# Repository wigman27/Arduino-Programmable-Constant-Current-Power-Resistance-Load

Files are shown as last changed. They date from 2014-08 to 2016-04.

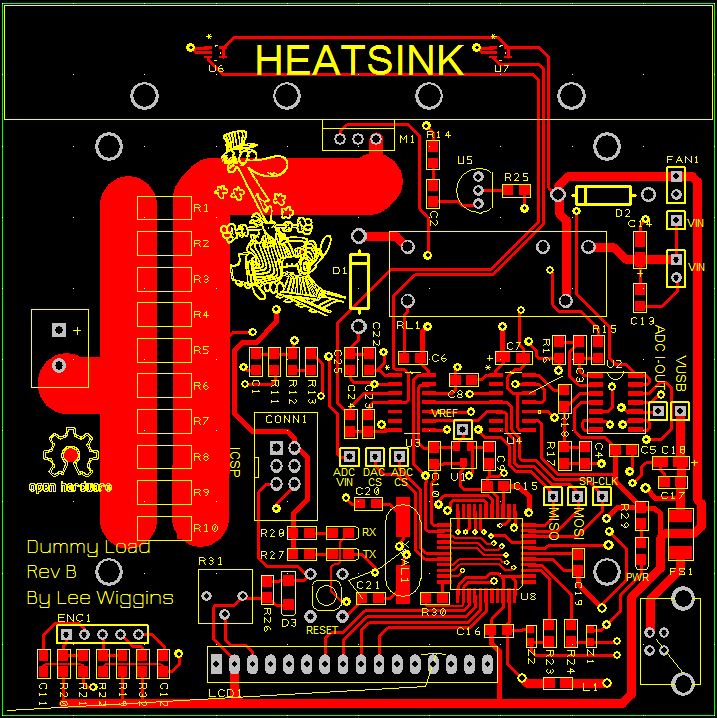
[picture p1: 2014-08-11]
Design Spark/rev 2/Top Layer.JPG

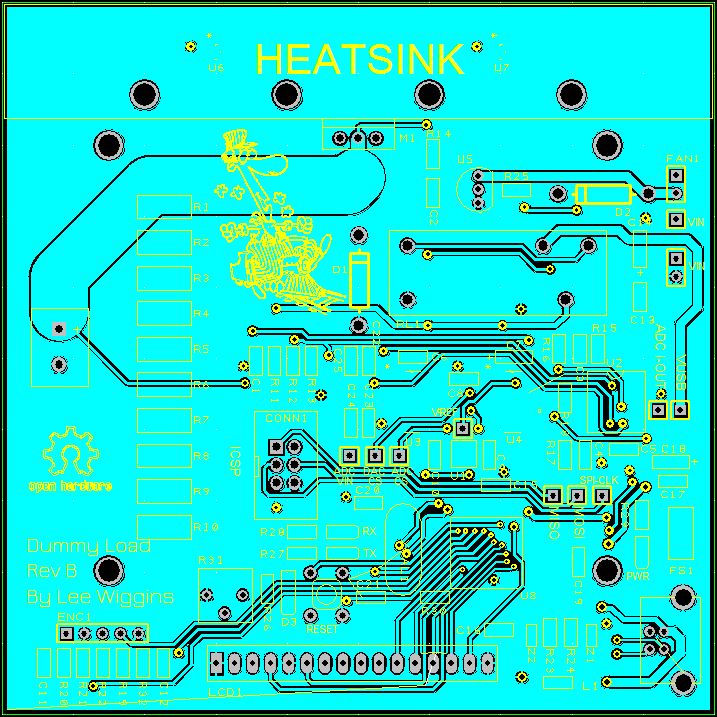
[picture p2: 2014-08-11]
Design Spark/rev 2/Bottom Layer.JPG

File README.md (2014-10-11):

Arduino-Programmable-Constant-Current-Power-Resistance-Load
===========================================================

This is all of the code, datasheets and design files for [my instructable](http://www.instructables.com/id/Arduino-Programmable-Constant-Current-Power-Resist/ "Arduino Programmable Constant Current Power Resistance Load") 

I also have boards available for sale on [Tindie](https://www.tindie.com/products/Wigman27/pcb-for-arduino-programmable-constant-current-power-resistance-load/) for $10 each
<p></p>

* Arduino - It contains the Arduino code that we will be talking about here, within the dummy load folder. It also contains all of the 3rd party libraries I have used.
* Datasheets - It contains all of the datasheets for the major components used within the project.
* DesignSpark - I have used the opensource schematic and PCB design software for this project, its a fantastic free tool that has no limitations and I find it easier to uses than Eagle - http://www.rs-online.com/designspark/electronics/eng/page/designspark-pcb-home-page The rev 1 folder contains all of my initial designs, please don't use this as there are 2 or 3 errors in the footprints plus I have completely revised the layout for rev 2, please only use these files. the gerber files are in there should you wish to have your own board done. See the next step for more information on this.
* LTSpice - This contains all of the LtSpice files from simulating the operation of the MOSFET.

Please checkout my instructable as it describes all of this code and the operation of the dummy load.

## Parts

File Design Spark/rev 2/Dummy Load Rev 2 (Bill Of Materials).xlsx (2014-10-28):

Ref Name | Qty | Component | Value | Package | Tolerance | Description | Element 14 Part Number | Digikey Part Number | eBay Item Number
C01 | 1 | Cap | 100n | 805 |  | Capacitor | 1759265 (https://au.element14.com/jsp/search/productdetail.jsp?SKU=1759265) | 1276-1007-1-ND (http://www.digikey.com/product-detail/en/CL21F104ZBCNNNC/1276-1007-1-ND/3889093)
C02 | 1 | Cap | 2.2uF | 805 |  | Capacitor | 2320829 (https://au.element14.com/jsp/search/productdetail.jsp?SKU=2320829) | 1276-1763-1-ND (http://www.digikey.com/product-detail/en/CL21A225KAFNNNE/1276-1763-1-ND/3889849)
C03 | 1 | Cap | 22n | 805 |  | Capacitor | 2320823 (https://au.element14.com/jsp/search/productdetail.jsp?SKU=2320823) | 1276-1081-1-ND (http://www.digikey.com/product-detail/en/CL21B223KBANNNC/1276-1081-1-ND/3889167)
C04 | 1 | Cap | 100n | 805 |  | Capacitor | 1759265 (https://au.element14.com/jsp/search/productdetail.jsp?SKU=1759265) | 1276-1007-1-ND (http://www.digikey.com/product-detail/en/CL21F104ZBCNNNC/1276-1007-1-ND/3889093)
C05 | 1 | Cap | 100n | 805 |  | Capacitor | 1759265 (https://au.element14.com/jsp/search/productdetail.jsp?SKU=1759265) | 1276-1007-1-ND (http://www.digikey.com/product-detail/en/CL21F104ZBCNNNC/1276-1007-1-ND/3889093)
C06 | 1 | Cap | 1uF | 805 |  | Capacitor | 2320827 (https://au.element14.com/jsp/search/productdetail.jsp?SKU=2320827) | 1276-1066-1-ND (http://www.digikey.com/product-detail/en/CL21B105KAFNNNE/1276-1066-1-ND/3889152)
C07 | 1 | Capacritor_Pol | 10uF | C1206POL |  |  | 1754182 (https://au.element14.com/jsp/search/productdetail.jsp?SKU=1754182) | 718-1123-1-ND (http://www.digikey.com/product-detail/en/293D106X9016A2TE3/718-1123-1-ND/1559617)
C08 | 1 | Cap | 100nF | 805 |  | Capacitor | 1759265 (https://au.element14.com/jsp/search/productdetail.jsp?SKU=1759265) | 1276-1007-1-ND (http://www.digikey.com/product-detail/en/CL21F104ZBCNNNC/1276-1007-1-ND/3889093)
C09 | 1 | Cap | 100n | 805 |  | Capacitor | 1759265 (https://au.element14.com/jsp/search/productdetail.jsp?SKU=1759265) | 1276-1007-1-ND (http://www.digikey.com/product-detail/en/CL21F104ZBCNNNC/1276-1007-1-ND/3889093)
C10 | 1 | Cap | 100n | 805 |  | Capacitor | 1759265 (https://au.element14.com/jsp/search/productdetail.jsp?SKU=1759265) | 1276-1007-1-ND (http://www.digikey.com/product-detail/en/CL21F104ZBCNNNC/1276-1007-1-ND/3889093)
C11 | 1 | Cap | 100n | 805 |  | Capacitor | 1759265 (https://au.element14.com/jsp/search/productdetail.jsp?SKU=1759265) | 1276-1007-1-ND (http://www.digikey.com/product-detail/en/CL21F104ZBCNNNC/1276-1007-1-ND/3889093)
C12 | 1 | Cap | 100n | 805 |  | Capacitor | 1759265 (https://au.element14.com/jsp/search/productdetail.jsp?SKU=1759265) | 1276-1007-1-ND (http://www.digikey.com/product-detail/en/CL21F104ZBCNNNC/1276-1007-1-ND/3889093)
C13 | 1 | Cap | 100nF | 805 |  | Capacitor | 1759265 (https://au.element14.com/jsp/search/productdetail.jsp?SKU=1759265) | 1276-1007-1-ND (http://www.digikey.com/product-detail/en/CL21F104ZBCNNNC/1276-1007-1-ND/3889093)
C14 | 1 | Capacritor_Pol | 10uF | C1206POL |  |  | 1754182 (https://au.element14.com/jsp/search/productdetail.jsp?SKU=1754182) | 718-1123-1-ND (http://www.digikey.com/product-detail/en/293D106X9016A2TE3/718-1123-1-ND/1559617)
C15 | 1 | Cap | 100n | 805 |  | Capacitor | 1759265 (https://au.element14.com/jsp/search/productdetail.jsp?SKU=1759265) | 1276-1007-1-ND (http://www.digikey.com/product-detail/en/CL21F104ZBCNNNC/1276-1007-1-ND/3889093)
C16 | 1 | Cap | 100n | 805 |  | Capacitor | 1759265 (https://au.element14.com/jsp/search/productdetail.jsp?SKU=1759265) | 1276-1007-1-ND (http://www.digikey.com/product-detail/en/CL21F104ZBCNNNC/1276-1007-1-ND/3889093)
C17 | 1 | Cap | 100nF | 805 |  | Capacitor | 1759265 (https://au.element14.com/jsp/search/productdetail.jsp?SKU=1759265) | 1276-1007-1-ND (http://www.digikey.com/product-detail/en/CL21F104ZBCNNNC/1276-1007-1-ND/3889093)
C18 | 1 | Capacritor_Pol | 10uF | C1206POL |  |  | 1754182 (https://au.element14.com/jsp/search/productdetail.jsp?SKU=1754182) | 718-1123-1-ND (http://www.digikey.com/product-detail/en/293D106X9016A2TE3/718-1123-1-ND/1559617)
C19 | 1 | Cap | 1uF | 805 |  | Capacitor | 2320827 (https://au.element14.com/jsp/search/productdetail.jsp?SKU=2320827) | 1276-1066-1-ND (http://www.digikey.com/product-detail/en/CL21B105KAFNNNE/1276-1066-1-ND/3889152)
C20 | 1 | Cap | 22p | 805 |  | Capacitor | 2332763 (https://au.element14.com/jsp/search/productdetail.jsp?SKU=2332763) | 1276-1047-1-ND (http://www.digikey.com/product-detail/en/CL21C220JBANNNC/1276-1047-1-ND/3889133)
C21 | 1 | Cap | 22p | 805 |  | Capacitor | 2332763 (https://au.element14.com/jsp/search/productdetail.jsp?SKU=2332763) | 1276-1047-1-ND (http://www.digikey.com/product-detail/en/CL21C220JBANNNC/1276-1047-1-ND/3889133)
C22 | 1 | Cap | 1uF | 805 |  | Capacitor | 2320827 (https://au.element14.com/jsp/search/productdetail.jsp?SKU=2320827) | 1276-1066-1-ND (http://www.digikey.com/product-detail/en/CL21B105KAFNNNE/1276-1066-1-ND/3889152)
C23 | 1 | Cap | 100n | 805 |  | Capacitor | 1759265 (https://au.element14.com/jsp/search/productdetail.jsp?SKU=1759265) | 1276-1007-1-ND (http://www.digikey.com/product-detail/en/CL21F104ZBCNNNC/1276-1007-1-ND/3889093)
C24 | 1 | Cap | 100n | 805 |  | Capacitor | 1759265 (https://au.element14.com/jsp/search/productdetail.jsp?SKU=1759265) | 1276-1007-1-ND (http://www.digikey.com/product-detail/en/CL21F104ZBCNNNC/1276-1007-1-ND/3889093)
C25 | 1 | Cap | 1uF | 805 |  | Capacitor | 2320827 (https://au.element14.com/jsp/search/productdetail.jsp?SKU=2320827) | 1276-1066-1-ND (http://www.digikey.com/product-detail/en/CL21B105KAFNNNE/1276-1066-1-ND/3889152)
CONN1 | 1 | ICSP-6 |  | DIL |  |  | 1508414 (https://au.element14.com/jsp/search/productdetail.jsp?SKU=1508414) | WM8247-ND (http://www.digikey.com/product-detail/en/0901301206/WM8247-ND/760959)
D1 | 1 | 1N4001 |  | DIOD05 |  |  | 1843694 (https://au.element14.com/jsp/search/productdetail.jsp?SKU=1843694) | 1N4001-TPMSCT-ND (http://www.digikey.com/product-detail/en/1N4001-TP/1N4001-TPMSCT-ND/773688)
D2 | 1 | 1N4001 |  | DIOD05 |  |  | 1843694 (https://au.element14.com/jsp/search/productdetail.jsp?SKU=1843694) | 1N4001-TPMSCT-ND (http://www.digikey.com/product-detail/en/1N4001-TP/1N4001-TPMSCT-ND/773688)
D3 | 1 | CD1206-S01575 |  | D1206 |  |  | 2211947 (https://au.element14.com/jsp/search/productdetail.jsp?SKU=2211947) | CD1206-S01575CT-ND (http://www.digikey.com/product-detail/en/CD1206-S01575/CD1206-S01575CT-ND/3741949)
ENC1 | 1 | ROTARY-ENCV |  | DIP-5 |  |  |  |  | 111415780070 (http://www.ebay.com/sch/i.html?_from=R40&_nkw=rotary+encoder&_sacat=0)
FAN1 | 1 | EB50100S2-0000-A99 |  | DIL |  |  | 1924834 (https://au.element14.com/jsp/search/productdetail.jsp?SKU=1924834) | 259-1558-ND (http://www.digikey.com/product-detail/en/MB50100V2-000U-A99/259-1558-ND/2757783)
FS1 | 1 | MF-MSMF050-2 | 500mA | 1812 |  |  | 2128216 (https://au.element14.com/jsp/search/productdetail.jsp?SKU=2128216) | MF-MSMF050-2CT-ND (http://www.digikey.com/product-detail/en/MF-MSMF050-2/MF-MSMF050-2CT-ND/662842)
J1 | 1 | USB-B |  | DIL |  |  | 1308876 (https://au.element14.com/jsp/search/productdetail.jsp?SKU=1308876) | ED2983-ND (http://www.digikey.com/product-detail/en/USB-B1HSB6/ED2983-ND/2677744)
L1 | 1 | 74279206-Ferrite Bead |  | 805 |  |  | 1635729 (https://au.element14.com/jsp/search/productdetail.jsp?SKU=1635729) | 732-1612-1-ND (http://www.digikey.com/product-detail/en/742792063/732-1612-1-ND/1639556)
LCD1 | 1 | HD44780 20x4 LCD |  | DIL |  |  |  |  | 400448319287 (http://www.ebay.com/itm/2004-204-20x4-Character-LCD-Display-Module-HD44780-Controller-Blue-Blacklight-/400448319287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)
LED1 | 1 | LED | TX Red | D0805 |  | Light Em Di | 2099236 (https://au.element14.com/jsp/search/productdetail.jsp?SKU=2099236) | 754-1128-1-ND (http://www.digikey.com/product-detail/en/APT2012EC/754-1128-1-ND/1747845)
LED2 | 1 | LED | RX Green | D0805 |  | Light Em Di | 2099239 (https://au.element14.com/jsp/search/productdetail.jsp?SKU=2099239) | 754-1131-2-ND (http://www.digikey.com/product-detail/en/APT2012SGC/754-1131-2-ND/1747530)
LED3 | 1 | LED | Pwr Green | D0805 |  | Light Em Di | 2099239 (https://au.element14.com/jsp/search/productdetail.jsp?SKU=2099239) | 754-1131-2-ND (http://www.digikey.com/product-detail/en/APT2012SGC/754-1131-2-ND/1747530)
M1 | 1 | BUK954R8-60E |  | DSC |  |  | 2254188 (https://au.element14.com/jsp/search/productdetail.jsp?SKU=2254188) | BUK954R8-60E,127 (http://www.digikey.com/product-search/en?KeyWords=BUK954R8-60E&WT.z_header=search_go)
PL1 | 1 | CONN_SIL_2 |  | DIP |  | 2 way Pin Header |  |  | 251273258816 (http://www.ebay.com.au/itm/New-40-Pin-2-54mm-Male-Female-SIL-Header-Socket-Single-Row-Strip-PCB-Connector-/251273258816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)
PL2 | 1 | CONN_SIL_2 |  | DSC |  | 2 way Pin Header |  |  | 251273258816 (http://www.ebay.com.au/itm/New-40-Pin-2-54mm-Male-Female-SIL-Header-Socket-Single-Row-Strip-PCB-Connector-/251273258816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)
R01 | 1 | Resistor | 1R0 | 2512 | 1% | Resistor | 2081851 (https://au.element14.com/jsp/search/productdetail.jsp?SKU=2081851) | PT1.0YCT-ND (http://www.digikey.com/product-detail/en/ERJ-1TRQF1R0U/PT1.0YCT-ND/613922)
R02 | 1 | Resistor | 1R0 | 2512 | 1% | Resistor | 2081851 (https://au.element14.com/jsp/search/productdetail.jsp?SKU=2081851) | PT1.0YCT-ND
R03 | 1 | Resistor | 1R0 | 2512 | 1% | Resistor | 2081851 | PT1.0YCT-ND
R04 | 1 | Resistor | 1R0 | 2512 | 1% | Resistor | 2081851 | PT1.0YCT-ND
R05 | 1 | Resistor | 1R0 | 2512 | 1% | Resistor | 2081851 | PT1.0YCT-ND
R06 | 1 | Resistor | 1R0 | 2512 | 1% | Resistor | 2081851 | PT1.0YCT-ND
R07 | 1 | Resistor | 1R0 | 2512 | 1% | Resistor | 2081851 | PT1.0YCT-ND
R08 | 1 | Resistor | 1R0 | 2512 | 1% | Resistor | 2081851 | PT1.0YCT-ND
R09 | 1 | Resistor | 1R0 | 2512 | 1% | Resistor | 2081851 | PT1.0YCT-ND
R10 | 1 | Resistor | 1R0 | 2512 | 1% | Resistor | 2081851 | PT1.0YCT-ND
R11 | 1 | Resistor | 220k | 805 | 0.10% | Resistor | 1577690 (https://au.element14.com/jsp/search/productdetail.jsp?SKU=1577690) | P220KDACT-ND (http://www.digikey.com/product-detail/en/ERA-6AEB224V/P220KDACT-ND/1466003)
R12 | 1 | Resistor | 10K | 805 | 0.10% | Resistor | 1577673 (https://au.element14.com/jsp/search/productdetail.jsp?SKU=1577673) | CRT0805-BY-1002ELFCT-ND (http://www.digikey.com/product-detail/en/CRT0805-BY-1002ELF/CRT0805-BY-1002ELFCT-ND/1775047)
R13 | 1 | Resistor | 10K | 805 | 0.10% | Resistor | 1577673 (https://au.element14.com/jsp/search/productdetail.jsp?SKU=1577673) | CRT0805-BY-1002ELFCT-ND (http://www.digikey.com/product-detail/en/CRT0805-BY-1002ELF/CRT0805-BY-1002ELFCT-ND/1775047)
R14 | 1 | Resistor | 2R2 | 805 |  | Resistor |  |  | 111428926233 (http://www.ebay.com/itm/0805-E12-SMDR-SMD-Resistor-Assorted-Kit-86-values-x-50-5-4300pcs-New-/111428926233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)
R15 | 1 | Resistor | 470R | 805 |  | Resistor |  |  | 111428926233 (http://www.ebay.com/itm/0805-E12-SMDR-SMD-Resistor-Assorted-Kit-86-values-x-50-5-4300pcs-New-/111428926233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)
R16 | 1 | Resistor | 1K | 805 |  | Resistor |  |  | 111428926233 (http://www.ebay.com/itm/0805-E12-SMDR-SMD-Resistor-Assorted-Kit-86-values-x-50-5-4300pcs-New-/111428926233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)
R17 | 1 | Resistor | 10K | 805 | 0.10% | Resistor | 1577673 (https://au.element14.com/jsp/search/productdetail.jsp?SKU=1577673) | CRT0805-BY-1002ELFCT-ND (http://www.digikey.com/product-detail/en/CRT0805-BY-1002ELF/CRT0805-BY-1002ELFCT-ND/1775047)
R18 | 1 | Resistor | 15K | 805 | 0.10% | Resistor | 1577675 (https://au.element14.com/jsp/search/productdetail.jsp?SKU=1577675) | P15KDACT-ND (http://www.digikey.com/product-detail/en/ERA-6AEB153V/P15KDACT-ND/1465975)
R19 | 1 | Resistor | 10K | 805 |  | Resistor |  |  | For these resistors I would suggest getting a generic pack of 0805 resistors that you can use in the future if you like 111428926233
R20 | 1 | Resistor | 10K | 805 |  | Resistor
R21 | 1 | Resistor | 10K | 805 |  | Resistor
R22 | 1 | Resistor | 10K | 805 |  | Resistor
R23 | 1 | Resistor | 22R | 805 |  | Resistor
R24 | 1 | Resistor | 22R | 805 |  | Resistor
R25 | 1 | Resistor | 560R | 805 |  | Resistor
R26 | 1 | Resistor | 10K | 805 |  | Resistor
R27 | 1 | Resistor | 470R | 805 |  | Resistor
R28 | 1 | Resistor | 470R | 805 |  | Resistor
R29 | 1 | Resistor | 470R | 805 |  | Resistor
R30 | 1 | Resistor | 10K | 805 |  | Resistor |  |  | 111428926233 (http://www.ebay.com/itm/0805-E12-SMDR-SMD-Resistor-Assorted-Kit-86-values-x-50-5-4300pcs-New-/111428926233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)
R31 | 1 | R_POT | 10k | pot2 |  | Potentiometer |  | 3362P-1-103LF (http://au.element14.com/bourns/3362p-1-103lf/pot-trimmer-10k-3-pin/dp/9354301) | 3362P-103LF-ND (http://www.digikey.com/product-detail/en/3362P-1-103LF/3362P-103LF-ND/1088412)
R32 | 1 | Resistor | 10K | 805 |  | Resistor |  |  | 111428926233 (http://www.ebay.com/itm/0805-E12-SMDR-SMD-Resistor-Assorted-Kit-86-values-x-50-5-4300pcs-New-/111428926233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)
RL1 | 1 | G6RN-1 5DC |  | DIL |  |  | 9949933 (https://au.element14.com/jsp/search/productdetail.jsp?SKU=9949933) | Z987-ND (http://www.digikey.com/product-detail/en/G6RN-1%20DC5/Z987-ND/260142)
SW1 | 1 | Pushbutton |  | DISC |  |  |  |  | 221432348499 (http://www.ebay.com/itm/100pcs-Tactile-Pushbutton-Switch-Momentary-Tact-LCD-Screen-Monitor-4pin-6-6-5mm-/221432348499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)
TP1 | 1 | Test Point |  | DIL |  |  |  |  | 251273258816 (http://www.ebay.com.au/itm/New-40-Pin-2-54mm-Male-Female-SIL-Header-Socket-Single-Row-Strip-PCB-Connector-/251273258816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)
TP10 | 1 | Test Point |  | DIL |  |  |  |  | 251273258816 (http://www.ebay.com.au/itm/New-40-Pin-2-54mm-Male-Female-SIL-Header-Socket-Single-Row-Strip-PCB-Connector-/251273258816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)
TP2 | 1 | Test Point |  | DIL |  |  |  |  | 251273258816
TP3 | 1 | Test Point |  | DIL |  |  |  |  | 251273258816
TP4 | 1 | Test Point |  | DIL |  |  |  |  | 251273258816
TP5 | 1 | Test Point |  | DIL |  |  |  |  | 251273258816
TP6 | 1 | Test Point |  | DIL |  |  |  |  | 251273258816
TP7 | 1 | Test Point |  | DIL |  |  |  |  | 251273258816
TP8 | 1 | Test Point |  | DIL |  |  |  |  | 251273258816
TP9 | 1 | Test Point |  | DIL |  |  |  |  | 251273258816
U1 | 1 | ADR380ARTZ |  | SOT23 |  |  | 2067815 (https://au.element14.com/jsp/search/productdetail.jsp?SKU=2067815) | ADR380ARTZ-REEL7CT-ND (http://www.digikey.com/product-detail/en/ADR380ARTZ-REEL7/ADR380ARTZ-REEL7CT-ND/1278862)
U2 | 1 | LM324 |  | SO14 |  | Quad Op Amp | 1262620 (https://au.element14.com/jsp/search/productdetail.jsp?SKU=1262620) | LM324AMX/NOPBCT-ND (http://www.digikey.com/product-detail/en/LM324AMX%2FNOPB/LM324AMX%2FNOPBCT-ND/1010531)
U3 | 1 | MCP3204-CI/SL |  | SOIC14-N_MC |  |  | 1196795 (https://au.element14.com/jsp/search/productdetail.jsp?SKU=1196795) | MCP3204T-CI/SLCT-ND (http://www.digikey.com/product-detail/en/MCP3204T-CI%2FSL/MCP3204T-CI%2FSLCT-ND/669497)
U4 | 1 | MCP4922-E/SL |  | SOIC14-N_MC |  |  | 1332114 (https://au.element14.com/jsp/search/productdetail.jsp?SKU=1332114) | MCP4922T-E/SLCT-ND (http://www.digikey.com/product-detail/en/MCP4922T-E%2FSL/MCP4922T-E%2FSLCT-ND/736003)
U5 | 1 | PN2222 |  | TO92 |  |  | 1695606 (http://au.element14.com/fairchild-semiconductor/pn2222atf/bipolar-transistor-npn-40v-to-92/dp/1695606) | PN2222AD26ZCT-ND (http://www.digikey.com/product-detail/en/PN2222ATFR/PN2222AD26ZCT-ND/459004)
U6 | 1 | LM94022BIMG |  | MAA05A |  |  | 1312600 (https://au.element14.com/jsp/search/productdetail.jsp?SKU=1312600) | LM94022BIMG/NOPBCT-ND (http://www.digikey.com/product-detail/en/LM94022BIMG%2FNOPB/LM94022BIMG%2FNOPBCT-ND/808023)
U7 | 1 | LM94022BIMG |  | MAA05A |  |  | 1312600 (https://au.element14.com/jsp/search/productdetail.jsp?SKU=1312600) | LM94022BIMG/NOPBCT-ND (http://www.digikey.com/product-detail/en/LM94022BIMG%2FNOPB/LM94022BIMG%2FNOPBCT-ND/808023)
U8 | 1 | ATmega32U4-AU |  | TQFP44 |  |  | 1748525 (https://au.element14.com/jsp/search/productdetail.jsp?SKU=1748525) | ATMEGA32U4-AURCT-ND (http://www.digikey.com/product-detail/en/ATMEGA32U4-AUR/ATMEGA32U4-AURCT-ND/3440960)
XTAL1 | 1 | AT-16.000MAGE-T |  | HC-49S |  |  | 2142522 (https://au.element14.com/jsp/search/productdetail.jsp?SKU=2142522) | 887-1608-1-ND (http://www.digikey.com/product-detail/en/AT-16.000MAGE-T/887-1608-1-ND/3182341)
Z1 | 1 | CG0603MLC-05E |  | 603 |  |  | 1838966 (https://au.element14.com/jsp/search/productdetail.jsp?SKU=1838966) | CG0603MLC-05ECT-ND (http://www.digikey.com/product-detail/en/CG0603MLC-05E/CG0603MLC-05ECT-ND/3438061)
Z2 | 1 | CG0603MLC-05E |  | 603 |  |  | 1838966 (https://au.element14.com/jsp/search/productdetail.jsp?SKU=1838966) | CG0603MLC-05ECT-ND (http://www.digikey.com/product-detail/en/CG0603MLC-05E/CG0603MLC-05ECT-ND/3438061)
 | 4 | PCB Stand-offs |  |  |  |  | 1466932 (https://au.element14.com/jsp/search/productdetail.jsp?SKU=1466932) | 9072-ND (http://www.digikey.com/product-detail/en/9072/9072-ND/4499377)
 | 4 | M3 Screws |  |  |  |  |  |  | 350820635884 (http://www.ebay.com/itm/50-pcs-M3-x-6mm-Philips-Head-Screw-/350820635884?pt=LH_DefaultDomain_0)
 | 1 | Heatsink |  | OS518-100-B |  |  | 1773364 (https://au.element14.com/jsp/search/productdetail.jsp?SKU=1773364) | Cannot Find
 | 1 | Heatsink Clip |  | MAX01G |  |  | 1773348 (https://au.element14.com/jsp/search/productdetail.jsp?SKU=1773348)
 | 1 | Thermal Pad |  | CM20-NA-314 |  |  | 1219149 (https://au.element14.com/jsp/search/productdetail.jsp?SKU=1219149)
 | 1 | Fan Guard |  | MC34243 |  |  | 1782871 (https://au.element14.com/jsp/search/productdetail.jsp?SKU=1782871)
 | 1 | Binding Post - Black |  |  |  |  | 173711301 (http://au.element14.com/jsp/search/productdetail.jsp?id=1737113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)
 | 1 | Binding Post - Red |  |  |  |  | 173711201 (http://au.element14.com/cliff-electronic-components/tp-6s-red-assembled/binding-post-30a-4mm-panel-red/dp/1737112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)

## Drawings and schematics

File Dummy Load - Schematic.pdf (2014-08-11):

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

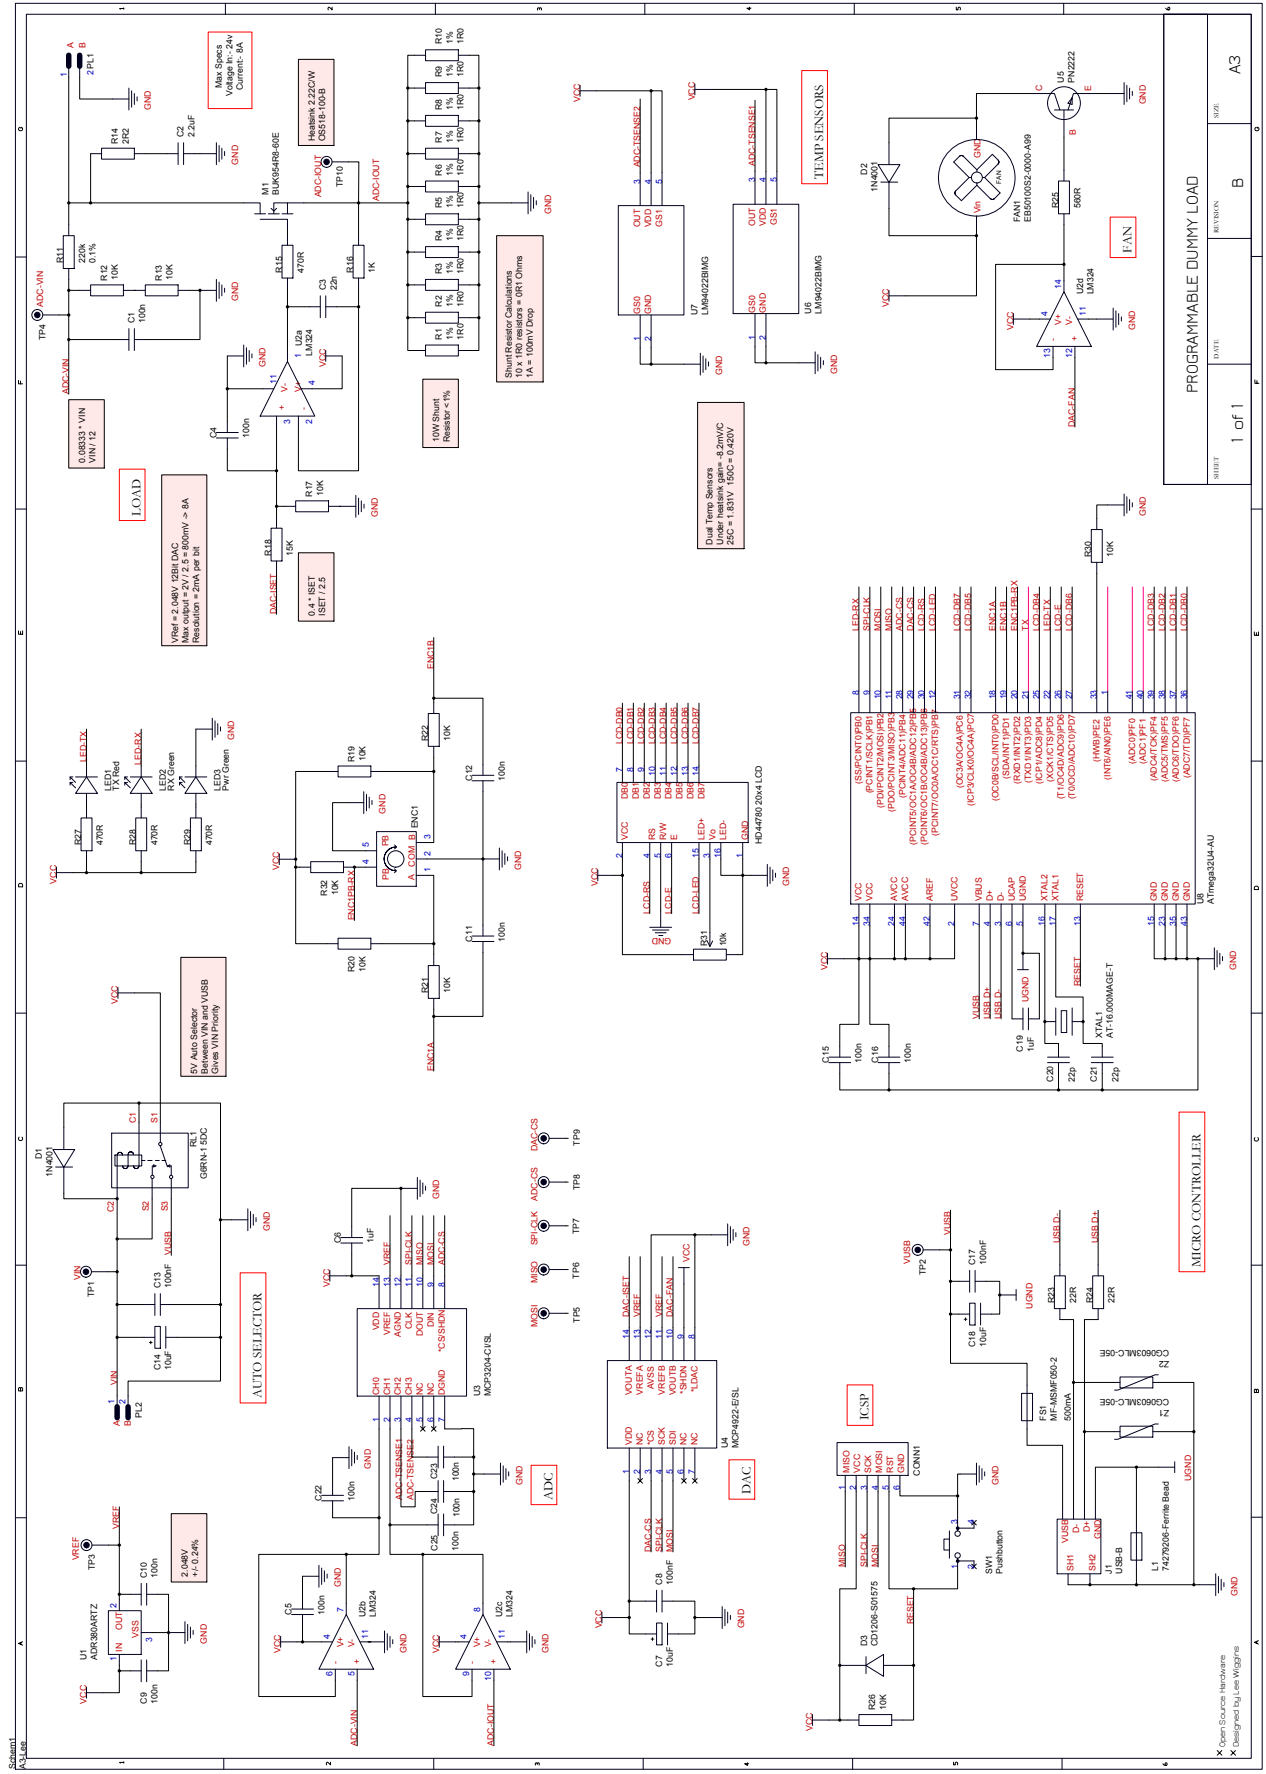
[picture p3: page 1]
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

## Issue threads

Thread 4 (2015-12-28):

Displaying multiple equal signs on the display

wigman27, 2015-12-28:
It powers up and shows the splash screen: "Dummy Load Version 1.11".
It then shows the next screen:
Voltage = 0.000V
Current = 0.000A
Resistancenan"ohm symbol"
Power = 0.000W
Immediately after that screen most text is replaced by an equal sign and space repeatedly on all four lines. It ends up looking something like the following
= = = = = =0.00V = =
= = = = = = = = = =
= = = = = nan"ohm symbol"= = =
= = = = == = = =

Sometimes the above screen is then replaced by solid blocks on lines 1 and 3 which are flickering with the screen refresh.

Closed 2016-04-01.

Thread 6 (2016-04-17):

BOM and Schematic

bohunter11, 2016-04-17:
I have found some conflicting values between the bom and schematic. Witch one is should I follow.
Thanks, Bo

wigman27, 2016-04-18:
Hi Bo,

Which ones are different?

Lee

bohunter11, 2016-04-19:
Well C22 and C25 show 1uf and the schematic shows 100nf. I haven't checked any others, I was just trying to figure out why CH1 on the ADC is not outputting any data when I put print statements in.

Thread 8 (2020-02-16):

Encoder button.

RAJensen, 2020-02-16:
Hi.
I'm building this fine piece of electronics.
But i have a little issue, The encoder that i use, have build-in RGB led and have common with the button. The encoder in schematic, is pulled high and triggers with low. Because my LED have (+) common with the button i need to change the code. But i have some trouble figuring out what is going on in ClickEncoder.h
In line 60 : ClickEncoder(uint8_t A, uint8_t B, uint8_t BTN = -1,
               uint8_t stepsPerNotch = 1, bool active = LOW);

Can i change bool active = LOW to bool active = HIGH to fit to my button or will that change, also affect the encoder A/B buttons?
In advance thank you.

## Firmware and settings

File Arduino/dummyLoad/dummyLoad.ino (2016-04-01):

/*
Version Control

1.00
* Initial upload

1.10
* Fixed an error in the set current function of the DAC
* Added improved current calculation to allow for correction in OP-AMP
* offset, uses the measured value to adjust the set current.
* General code tidy up

1.11
* Added prefixes to constants and gobal variables
* added named constants to DAC equation
* added the roundFloat function

To - Dos

* Improve push button functions to allow the encode to set the
  individual values ie. 10s, 1s, 0.s, 0.1s, 0.01s and 0.001s
* Display in engineering units, ie. mA and mW.
* Add PWM control to LCD backlight.

*/

// Please select your language
#define ENGLISH
//#define GERMAN

// include the library code:
#include <LiquidCrystal.h>
#include <SPI.h>
#include <ClickEncoder.h>
#include <TimerOne.h>

// Set Constants
// set pin 8 as the chip select for the ADC:
const int k_adcChipSelectPin = 8;
// set the ADC channel that reads the input voltage.
const int k_adcInputVoltage = 0;
// set the ADC channel that reads the input current by measuring the voltage on
// the input side of the sense resistors.
const int k_adcMeasuredCurrent = 1;
// set the ADC channel that reads the temprature sensor 1 under the heatsink.
const int k_adcTempSense1 = 2;
// set the ADC channel that reads the temprature sensor 2 under the heatsink.
const int k_adcTempSense2 = 3;

// set pin 9 as the chip select for the DAC:
const int k_dacChipSelectPin = 9;
// set The DAC channel that sets the constant current.
const int k_dacCurrentSet = 0;
// set The DAC channel that sets the fan speed.
const int k_dacFanSet = 1;

const float k_senseResistor = 0.1;
const float k_voltageRatio = 2.5;
const float k_voltageReference = 2.048;
const int k_dacResolution = 4096;

// set pin 3 as the channel A for encoder 1, int.0:
const int k_encoderA = 3;
// set pin 2 as the channel B for encoder 1, int.1:
const int k_encoderB = 2;
// set pin 0 as the push button for encoder 1
const int k_encoderPBPin = 0;

// LCD Backlight
const int k_ledBacklight = 11;

// Menu constants
// Constant used for the LCD to display the values
const int k_displayValues = 0;
// Constant used for the LCD to display the menu
const int k_displayMenu = 1;

// Languages
#ifdef ENGLISH
char const *language_name = "Dummy Load";
char const *language_version = "Version ";
char const *language_voltage = "Voltage";
char const *language_current = "Current";
char const *language_resistance = "Resistance";
char const *language_power = "Power";
char const *language_mode = "Please Select Mode";
char const *language_cancel = "Cancel";
#endif

#ifdef GERMAN
char const *language_name = "Elekronische Last";
char const *language_version = "Version ";
char const *language_voltage = "Spannung";
char const *language_current = "Strom";
char const *language_resistance = "Widerstand";
char const *language_power = "Leistung";
char const *language_mode = "Bitte Modus wählen";
char const *language_cancel = "Abbrechen";
#endif

// Modes of operations
// Represents the constant current mode
const int k_currentMode = 0;
// Represents the constant resistance mode
const int k_resistanceMode = 1;
// Represents the constant power mode
const int k_powerMode = 2;

// Set integers for maximum values.
// Maximum Value of load current
const int k_maximumCurrent = 8;
// Maximum power dissipated
const int k_maximumPower = 50;

// used for the current software version
const float k_softwareVersion = 1.11;

// Set Integers
// variable to store the old encoder position.
int g_encoderOldPos = -1;
// variable to store the new encoder position.
int g_encoderPos = 0;
// variable to store the LCD display mode, ie. Menu or Values.
int g_lcdDisplay = 0;
// Which menu is selected when the button is pushed.
int g_selectedMenu = 0;
// variable to store the mode the unit is in, ie. Constant Current, Resistance
// or Power.
int g_mode = 0;

// Set Floats
// Float that stores the input voltage.
float g_inputVoltage = 0;
// Float that stores the measured current through the sustem.
float g_measuredCurrent = 0;
// Used to round the float values to minamise DAC communications.
float g_roundedMeasuredCurrent = 0;
// Float that stores the current sent to the DAC.
float g_setCurrent = 0;
// Float that stores the calculated system resistance.
float g_setResistance = 0;
// Float that stores the calculated system power.
float g_setPower = 0;
float g_adjustedCurrent = 0;

// Used to refresh LCD display.
unsigned long g_timeSinceLastDisplay = 0;

// Set Encoder
ClickEncoder *encoder;
// boolean to store if the encoder has moved.
boolean encoderMoved = false;

void timerIsr() {
  // Used by the encoder library.
  encoder->service();
}

// initialize the library with the numbers of the interface pins
//   ATMega32U4 Pins RS-30, E-26, D4-25, D5-32, D6-27, D7-31.
LiquidCrystal lcd(10, 12, 4, 13, 6, 5);

// Start of custom functions:

// Function to set the DAC, Accepts the Value to be sent and the
// cannel of the DAC to be used.
void setDac(int value, int channel) {

  // Sets default DAC registers B00110000, 1st bit choses DAC, A=0 B=1,
  // 2nd Bit bypasses input Buffer, 3rd bit sets output gain to 1x, 4th
  // bit controls active low shutdown. LSB are insignifigant here.
  byte dacRegister = 0b00110000;

  // Isolates the last 8 bits of the 12 bit value, B0000000011111111.
  int dacSecondaryByteMask = 0xFF;

  // Value is a maximum 12 Bit value, it is shifted to the right
  // by 8 bytes to get the first 4 MSB out of the value for
  // entry into th Primary Byte, then ORed with the dacRegister
  byte dacPrimaryByte = (value >> 8) | dacRegister;

  // compares the 12 bit value to isolate the 8 LSB and reduce it to a single
  // byte.
  byte dacSecondaryByte = value & dacSecondaryByteMask;

  // Sets the MSB in the primaryByte to determine the DAC to be set, DAC A=0,
  // DAC B=1
  switch (channel) {
  case 0:
    dacPrimaryByte &= ~(1 << 7);
    break;
  case 1:
    dacPrimaryByte |= (1 << 7);
  }
  // disable interupts to prepare to send data to the DAC
  noInterrupts();
  // take the Chip Select pin low to select the DAC:
  digitalWrite(k_dacChipSelectPin, LOW);
  //  send in the Primary Byte:
  SPI.transfer(dacPrimaryByte);
  // send in the Secondary Byte
  SPI.transfer(dacSecondaryByte);
  // take the Chip Select pin high to de-select the DAC:
  digitalWrite(k_dacChipSelectPin, HIGH);
  // Enable interupts
  interrupts();
}

// Function to read the ADC, accepts the channel to be read.
float readAdc(int channel) {

  // Sets default Primary ADC Address register B00000110,
  // This is a default address setting, the third LSB is
  // set to one to start the ADC, the second LSB is to set
  // the ADC to single ended mode, the LSB is for D2
  // address bit, for this ADC its a "Don't Care" bit.
  byte adcPrimaryRegister = 0b00000110;
  // b00000111 Isolates the three LSB.
  byte adcPrimaryRegisterMask = 0b00000111;

  // ensures the adc register is limited to the mask and
  // assembles the configuration byte to send to ADC.
  byte adcPrimaryConfig = adcPrimaryRegister & adcPrimaryRegisterMask;

  byte adcSecondaryConfig = channel << 6;

  // disable interupts to prepare to send address data to the ADC.
  noInterrupts();

  // take the Chip Select pin low to select the ADC.
  digitalWrite(k_adcChipSelectPin, LOW);

  //  send in the primary configuration address byte to the ADC.
  SPI.transfer(adcPrimaryConfig);

  // read the primary byte, also sending in the secondary address byte.
  byte adcPrimaryByte = SPI.transfer(adcSecondaryConfig);

  // read the secondary byte, also sending 0 as this doesn't matter.
  byte adcSecondaryByte = SPI.transfer(0x00);

  // take the Chip Select pin high to de-select the ADC.
  digitalWrite(k_adcChipSelectPin, HIGH);

  // Enable interupts.
  interrupts();

  // b00001111 isolates the 4 LSB for the value returned.
  byte adcPrimaryByteMask = 0b00001111;
  // Limits the value of the primary byte to the 4 LSB:
  adcPrimaryByte &= adcPrimaryByteMask;
  // Shifts the 4 LSB of the primary byte to become the 4 MSB of the 12
  // bit digital value, this is then ORed to the secondary byte value
  // that holds the 8 LSB of the digital value.
  int digitalValue = (adcPrimaryByte << 8) | adcSecondaryByte;

  // The digital value is converted to an analogue voltage using a VREF of
  // 2.048V.
  float value = (float(digitalValue) * 2.048) / 4096.000;

  // Returns the value from the function
  return value;
}

// Function to read the input voltage and return a float number represention
// volts.
void readInputVoltage() {
  g_inputVoltage = (readAdc(k_adcInputVoltage)) * 12.03;
  if (g_inputVoltage < 0.018) {
    g_inputVoltage = 0;
  }
}

// Function to measure the actual load current.
void readMeasuredCurrent() {
  g_measuredCurrent = (readAdc(k_adcMeasuredCurrent)) / 0.1000;
}

// This the best way I can think of rounding a floating point number
// to X decimal places.
float roundFloat(float number, int decimals) {
  float rounded_float = round(number * pow(10, decimals)) / pow(10, decimals);
  return rounded_float;
}

// Function to calculate and set the required load current. Accepts
// the mode variable to determine if the constant current, resistance
// or power mode is to be used.
void setLoadCurrent(int setMode) {
  // To ensure the encoder position is not
  // taken from the menu.
  if (g_lcdDisplay != k_displayMenu) {
    switch (setMode) {
    case 0:
      // Current Mode
      g_setCurrent =
          g_encoderPos /
          500.000; // as the DAC is capable of increasing the current in 0.002A
      if (g_setCurrent < 0)
        g_setCurrent = 0;
      if (g_setCurrent > k_maximumCurrent)
        g_setCurrent = k_maximumCurrent;
      g_setPower = g_inputVoltage * g_setCurrent;
      // Safety feature to ensure the maximum power value is not exceeded.
      if (g_setPower > k_maximumPower) {
        g_setCurrent = k_maximumPower / g_inputVoltage;
        g_encoderPos = int(g_setCurrent * 500.000);
      }
      // Calculate set resistance
      g_setResistance = g_inputVoltage / g_setCurrent;
      break;
    case 1:
      // Resistance Mode
      g_setResistance = g_encoderPos / 100.000;
      if (g_setResistance < 0)
        g_setResistance = 0;
      g_setCurrent = g_inputVoltage / g_setResistance;
      // Safety feature to ensure the maximum current value is not exceeded.
      if (g_setCurrent > k_maximumCurrent) {
        g_setCurrent = k_maximumCurrent;
        g_setResistance = g_inputVoltage / k_maximumCurrent;
        g_encoderPos = int(g_setResistance * 100.00);
      }
      g_setPower = g_inputVoltage * g_setCurrent;
      // Safety feature to ensure the maximum power value is not exceeded.
      if (g_setPower > k_maximumPower) {
        g_setCurrent = k_maximumPower / g_inputVoltage;
        g_setResistance = k_maximumPower / (g_setCurrent * g_setCurrent);
        g_encoderPos = int(g_setResistance * 100.00);
      }
      break;
    case 2:
      // Power Mode
      g_setPower = g_encoderPos / 100.000;
      if (g_setPower < 0)
        g_setPower = 0;
      if (g_setPower > k_maximumPower)
        g_setPower = k_maximumPower;
      g_setCurrent = g_setPower / g_inputVoltage;
      // Safety feature to ensure the maximum current value is not exceeded.
      if (g_setCurrent > k_maximumCurrent) {
        g_setCurrent = k_maximumCurrent;
        g_setPower = g_inputVoltage * k_maximumCurrent;
        g_encoderPos = int(g_setPower * 100.00);
      }
      // Calculate set resistance
      g_setResistance = g_inputVoltage / g_setCurrent;
      break;
    }
  }
  // Convert the set current into a voltage to be sent to the DAC
  readMeasuredCurrent();
  // To ensure we are not dividing by 0.
  if (g_measuredCurrent != 0) {
    // Turn the current error between set and measured into a
    // percentage so it can be adjusted
    g_adjustedCurrent = (g_setCurrent / g_measuredCurrent) * g_setCurrent;
  } else {
    g_adjustedCurrent = g_setCurrent;
  }
  g_roundedMeasuredCurrent = roundFloat(g_measuredCurrent, 3);
  // only adjust the current of the set and meausred currents are
  // diferent.
  if (g_roundedMeasuredCurrent != g_setCurrent) {
    int dacCurrent = ((g_adjustedCurrent * k_senseResistor * k_voltageRatio) /
                      k_voltageReference) *
                     k_dacResolution;
    // Send the value to the DAC.
    setDac(dacCurrent, k_dacCurrentSet);
  }
}

// Function to read heat sink temp
int readTemp() {
  float tempSensor1 = readAdc(k_adcTempSense1);
  float tempSensor2 = readAdc(k_adcTempSense2);
  // This takes an average of bothe temp sensors and converts the value
  // to millivolts
  float tempVoltage = ((tempSensor1 + tempSensor2) / 2) * 1000;
  // This comes from the datasheet to calculate the temp from the
  // voltage given.
  int temp = ((tempVoltage - 1885) / -11.2692307) + 20;
  return temp;
}

// Function to set the fan speed depending on the heatsink temprature.
void setFanSpeed() {
  int heatSinkTemp = readTemp();
  if (heatSinkTemp <= 30) {
    setDac(0, k_dacFanSet);
  }
  if (heatSinkTemp > 30) {
    setDac(2000, k_dacFanSet);
  }
  if (heatSinkTemp > 40) {
    setDac(2250, k_dacFanSet);
  }
  if (heatSinkTemp > 50) {
    setDac(2500, k_dacFanSet);
  }
  if (heatSinkTemp > 60) {
    setDac(2750, k_dacFanSet);
  }
  if (heatSinkTemp > 70) {
    setDac(3000, k_dacFanSet);
  }
}

// Function to allow the display to update every 0.5 seconds.
boolean updateDisplay() {
  unsigned long now = millis();
  if (now - g_timeSinceLastDisplay >= 500) {
    g_timeSinceLastDisplay = now;
    return true;
  } else {
    return false;
  }
}

// Function to set the mode of operation, ie, constant current,
// resistance or power.
void setMode(int menuMode) { g_mode = menuMode; }

/*
Function to update the LCD. Accepts the LCD display variable to set to
values or menu.  This determines what is on the LCD, case 0 means it
is in mormal mode and displays the values that everyting is set to it
also includes a less than symbol to show what mode it is in on the
screen. In this mode it tests if 500ms has passed, if so, it clears
the LCD and updates all the values. If you press the button on the
encoder it will activate the showmenu function further down which will
update the displaytype so it will then equal displayMenu, which equals
a const int of 1, as set above it will then satisfy case 1 below and
update the LCD to the menu functions.
*/
void updateLCD(int displayType) {
  // 20 char display
  char buf[21];
  switch (displayType) {
  case 0:
    if (updateDisplay()) {
      lcd.clear();
      sprintf(buf, "%s = ", language_voltage);
      lcd.print(buf);
      lcd.setCursor(10, 0);
      lcd.print(g_inputVoltage, 3);
      lcd.print("V");
      lcd.setCursor(0, 1);
      sprintf(buf, "%s =", language_current);
      lcd.print(buf);
      lcd.setCursor(10, 1);
      lcd.print(g_setCurrent, 3);
      lcd.print("A");
      if (g_mode == k_currentMode) {
        lcd.setCursor(19, 1);
        lcd.print("<");
      }
      lcd.setCursor(0, 2);
      sprintf(buf, "%s =", language_resistance);
      lcd.print(buf);
      lcd.setCursor(10, 2);
      lcd.print(g_setResistance, 3);
      lcd.print(char(0xF4));
      if (g_mode == k_resistanceMode) {
        lcd.setCursor(19, 2);
        lcd.print("<");
      }
      lcd.setCursor(0, 3);
      sprintf(buf, "%s =", language_power);
      lcd.print(buf);
      lcd.setCursor(10, 3);
      lcd.print(g_setPower, 3);
      lcd.print("W");
      if (g_mode == k_powerMode) {
        lcd.setCursor(19, 3);
        lcd.print("<");
      }
    }
    break;
  case 1:
    int menuItems = 3;
    if (g_encoderPos < 0)
      g_encoderPos = menuItems;
    if (g_encoderPos > menuItems)
      g_encoderPos = 0;
    if (encoderMoved || updateDisplay()) {
      lcd.clear();
      lcd.setCursor(1, 0);
      lcd.print(language_mode);
      lcd.setCursor(2, 2);
      switch (g_encoderPos) {
      case 0:
        lcd.print(language_current);
        break;
      case 1:
        lcd.print(language_resistance);
        break;
      case 2:
        lcd.print(language_power);
        break;
      case 3:
        lcd.print(language_cancel);
        break;
      }
    }
    break;
  }
}

/*
This function is called when the encoder button is pressed.

If the LCD is not displaying the menu, it must mean that we want the
menu, so it changes the lcdDisplay to display the menu, if we are in
the menu it must mean that we want to select that mode, it then
changes the mode, and redisplays the values.
*/
void showMenu() {
  if (g_lcdDisplay != k_displayMenu) {
    g_lcdDisplay = k_displayMenu;
    g_encoderPos = g_mode;
  } else {
    int menuMode = g_encoderPos;
    switch (menuMode) {
    case 0:
      // Current Mode
      setMode(k_currentMode);
      break;
    case 1:
      // Resistance Mode
      setMode(k_resistanceMode);
      break;
    case 2:
      // Power Mode
      setMode(k_powerMode);
      break;
    case 3:
      // Do Nothing, Cancel
      break;
    }
    g_lcdDisplay = k_displayValues;
  }
}

// Start setup function:
void setup() {
  // attach interrupts:
  attachInterrupt(
      2, showMenu,
      FALLING); // Sets encoder button interrupt on transition from high to low.
  // set outputs:
  pinMode(k_adcChipSelectPin, OUTPUT);
  pinMode(k_dacChipSelectPin, OUTPUT);
  pinMode(k_ledBacklight, OUTPUT);
  // set inputs:
  pinMode(k_encoderA, INPUT);
  pinMode(k_encoderB, INPUT);
  // set the ChipSelectPins high initially:
  digitalWrite(k_adcChipSelectPin, HIGH);
  digitalWrite(k_dacChipSelectPin, HIGH);
  // set the LCD Backlight high
  digitalWrite(k_ledBacklight, HIGH);
  // initialise SPI:
  SPI.begin();
  // Not strictly needed but just to be sure.
  SPI.setBitOrder(MSBFIRST);
  // Not strictly needed but just to be sure.
  SPI.setDataMode(SPI_MODE0);
  // Set SPI clock divider to 16, therfore a 1 MhZ signal due to the maximum
  // frequency of the ADC.
  SPI.setClockDivider(SPI_CLOCK_DIV16);
  // initialise encoder and associated timers:
  encoder = new ClickEncoder(k_encoderA, k_encoderB, k_encoderPBPin);
  Timer1.initialize(1000);
  Timer1.attachInterrupt(timerIsr);
  // set up the LCD's number of columns and rows:
  lcd.begin(20, 4);
  // Print a message to the LCD.
  lcd.setCursor(5, 1);
  lcd.print(language_name);
  lcd.setCursor(4, 2);
  lcd.print(language_version);
  lcd.print(k_softwareVersion);
  delay(1000);
  Serial.begin(9600);
} // End setup function.

// Start loop function:
void loop() {
  g_encoderPos += encoder->getValue();
  if (g_encoderPos != g_encoderOldPos) {
    encoderMoved = true;
    g_encoderOldPos = g_encoderPos;
  } else {
    encoderMoved = false;
  }
  // Reads input voltags from the load source.
  // ****MAXIMUM 24V INPUT****
  readInputVoltage();
  // Calculates and sets required load current. Accepts the mode
  // variable which defines the mode of the unit, ie. Constant
  // current, resistance or power.
  setLoadCurrent(g_mode);
  // Calculates heatsink temprature and sets fan speed accordingly.
  setFanSpeed();
  // Updates the LCD display. Accepts the lcdDisplay variable which
  // defines if the values or menu is to be displayed.
  updateLCD(g_lcdDisplay);
} // End of loop function.

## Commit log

2014-08-11 Initial Commit
    These files are all part of the initial commit. See readme.md for more
    information
    [Dummy Load - Rev1 (Bill Of Materials).csv, Dummy Load - Rev1 (Bill Of Materials).xlsx, Dummy Load - Rev1.sch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]
2014-08-11 Updated Bill of Materials
    Minor changes
    [Dummy Load Rev 2 (Bill Of Materials).xlsx]
2014-08-13 Updated BOM
    Updated the Bill of materials to include Element14 and Digikey links
    [Dummy Load Rev 2 (Bill Of Materials).csv, Dummy Load Rev 2 (Bill Of Materials).xlsx]
2014-08-13 Updated to Version 1.1 for software
    * Fixed an error in the set current function of the DAC
    * Added improved current calculation to allow for correction in OP-AMP
    offset, uses the measured value to adjust the set current.
    * General code tidy up
    Added a few things to the BOM that I had forgotten
    [Dummy Load Rev 2 (Bill Of Materials).xlsx]
2014-10-28 Added Top Solder Paste Stencil
    Added paste stencil and minor chances to BOM
    [Dummy Load Rev 2 (Bill Of Materials).xlsx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]
2014-12-30 Update dummyLoad.ino
    fixed percentage formula for adjusted current
    [dummyLoad.ino]
2014-12-30 Update dummyLoad.ino
    added change log and cleaned up DAC voltage equation
2014-12-30 Update dummyLoad.ino
    fixed adjusted current equation
    [dummyLoad.ino]
2015-01-02 Update dummyLoad.ino
    - reverted current equation
    - added some missing g_ prefixes
    - added a roundFloat function
    [dummyLoad.ino]
2015-01-02 Update dummyLoad.ino
    updated adjusted current calculation
2015-01-02 Update dummyLoad.ino
    fixed variable style errors
    [dummyLoad.ino]
2015-01-04 Update dummyLoad.ino
    reverted to original current measurements
    [dummyLoad.ino]
2015-01-05 Update dummyLoad.ino
    A minor typo correction.
    [dummyLoad.ino]
2015-01-05 Removal of Rev 1
    Removed all of rev 1 design files to save confusion
    [Dummy Load - Rev1 (Bill Of Materials).csv, Dummy Load - Rev1 (Bill Of Materials).xlsx, Dummy Load - Rev1.sch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]
2016-03-31 Fix warnings about string constants
    Fix "deprecated conversion" string warning
    [dummyLoad.ino]
2016-03-31 Rearrange to avoid prototypes
    There are no prototypes for several functions, so move
    things around so they are declared before use
    [dummyLoad.ino]
2016-03-31 Don't strcat over fixed string
    This is writing past the end of the string. Keep
    a separate buffer for constructing the messages
    [dummyLoad.ino]
2016-03-31 Add Makefile
    Add a Makefile and put the libraries in place so the arudino
    makefile can handle things automatically.
    With arduino-mk installed you should just be able to type
    "make upload" to get things going
